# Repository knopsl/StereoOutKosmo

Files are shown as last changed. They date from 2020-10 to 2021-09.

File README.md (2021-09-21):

# Stereo output / Kosmo

Stereo output synthesizer module in Kosmo format.

This is somewhat based on the [Barton Stereo Outs](https://www.bartonmusicalcircuits.com/stereoouts/index.html)  module. There are four AC coupled inputs with pan and level controls. 

The headphone output section is based on the LM4808 datasheet circuit. This is an SMD (SOIC-8) part; all other components are through hole.

I've built this but my mechanical design was frankly stupid. I ended up kludging it together in a somewhat horrible way. I have eliminated the PCB design file and Gerbers from this repository; do better ones yourself! The circuit design is fine as far as I can see. So is the front panel except the slider mounting screws holes would be eliminated if I were to do it over.

## Photo

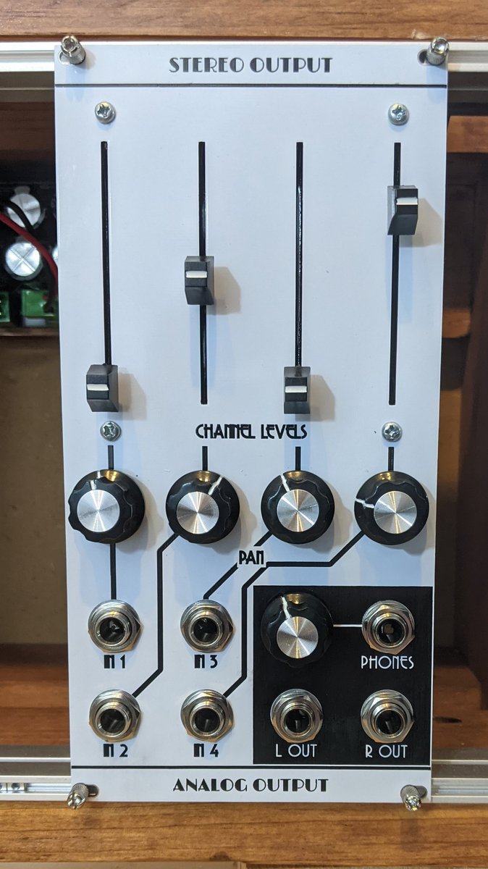
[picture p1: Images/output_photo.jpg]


## Documentation:

* [Schematic](Docs/ao_output.pdf)
* [BOM](Docs/ao_output_bom.md)

## Submodules

This repo uses submodules aoKicad and Kosmo_panel, which provide needed libaries for KiCad. To clone:

```
git clone git@github.com:holmesrichards/audiomixer.git
git submodule init
git submodule update
```

Alternatively do

```
git clone --recurse-submodules git@github.com:holmesrichards/audiomixer.git
```

Or if you download the repository as a zip file, you must also click on the "aoKicad" and "Kosmo\_panel" links on the GitHub page (they'll have "@ something" after them) and download them as separate zip files which you can unzip into this repo's aoKicad and Kosmo\_panel directories.

If desired, copy the files from aoKicad and Kosmo\_panel to wherever you prefer (your KiCad user library directory, for instance, if you have one). Then in KiCad, add symbol libraries 

```
aoKicad/ao_symbols
Kosmo_panel/Kosmo
```
and footprint libraries 
```
aoKicad/ao_tht
Kosmo_panel/Kosmo_panel.
```

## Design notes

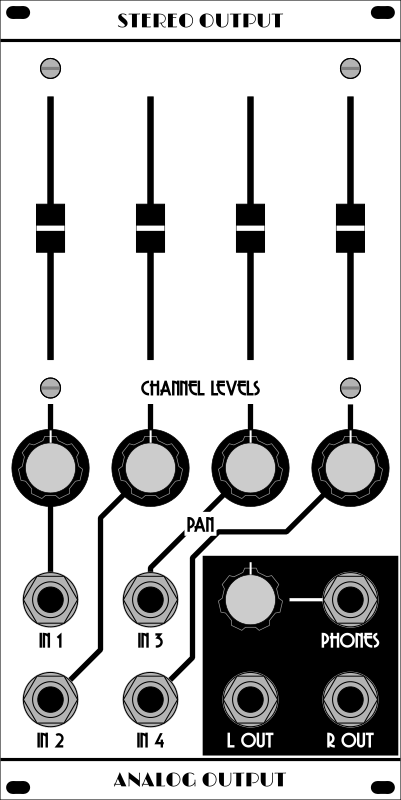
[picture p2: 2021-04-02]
Hardware/Panel/ao_output_panel_slide.png

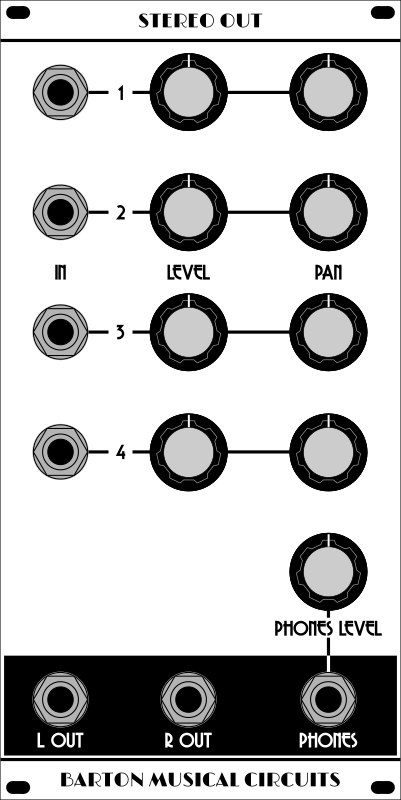
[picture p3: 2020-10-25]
Hardware/Panel/ao_output_panel.png

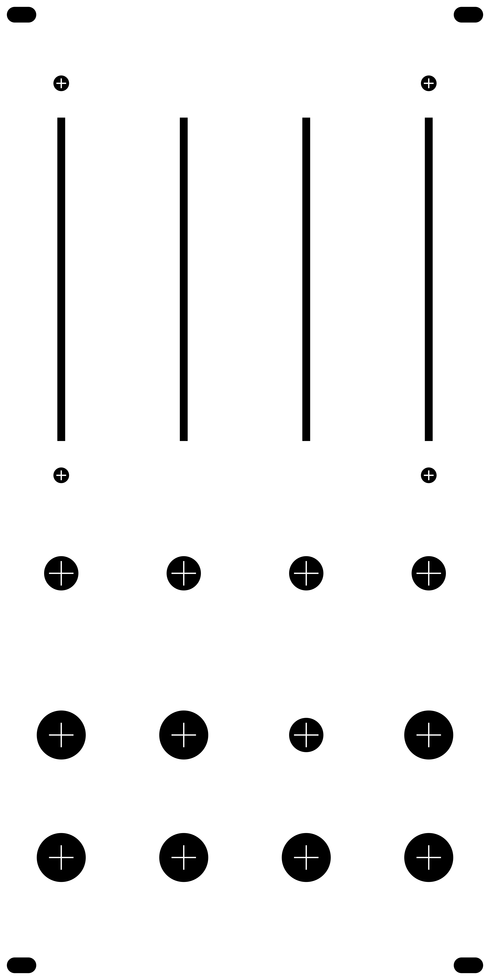
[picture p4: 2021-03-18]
Hardware/Panel/ao_output_panel_slide_holes.png

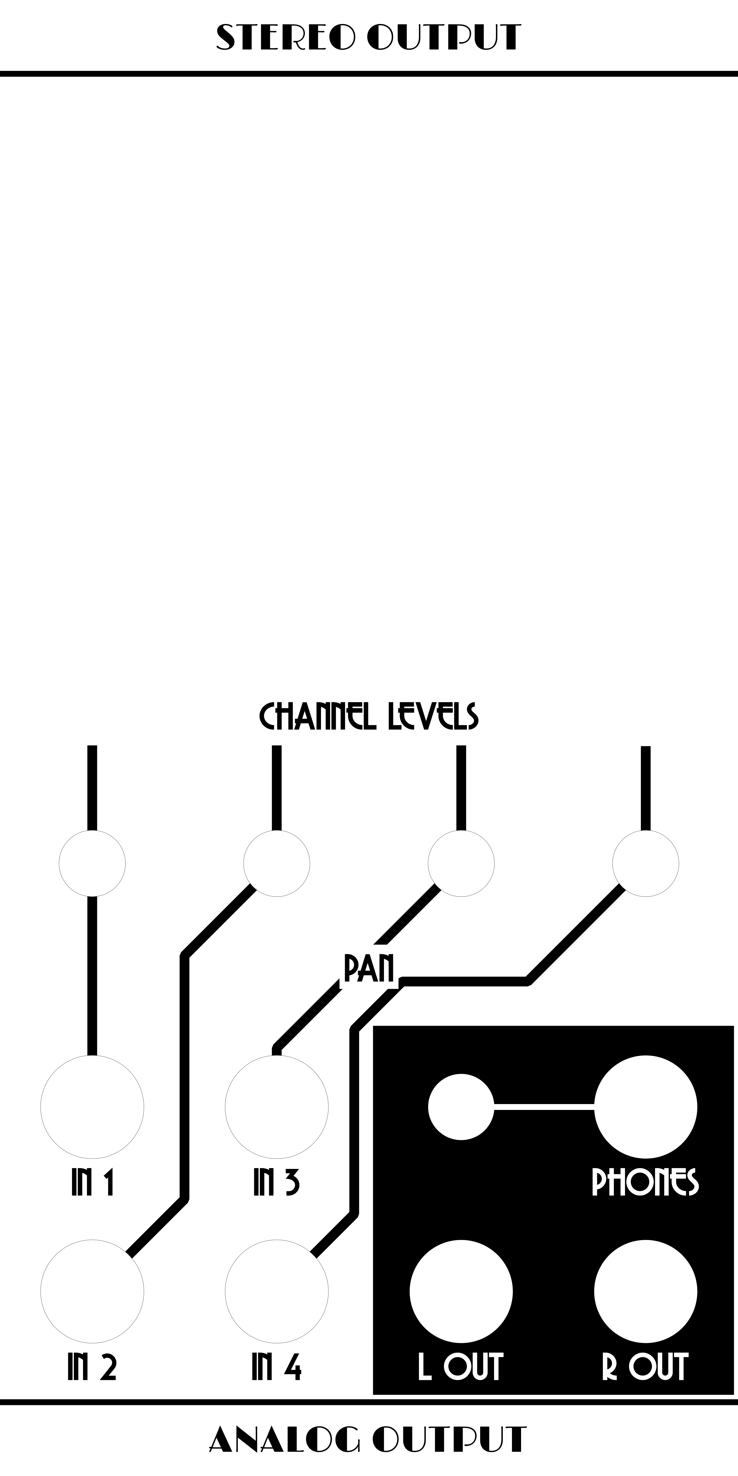
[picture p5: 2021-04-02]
Hardware/Panel/ao_output_panel_slide_art.png

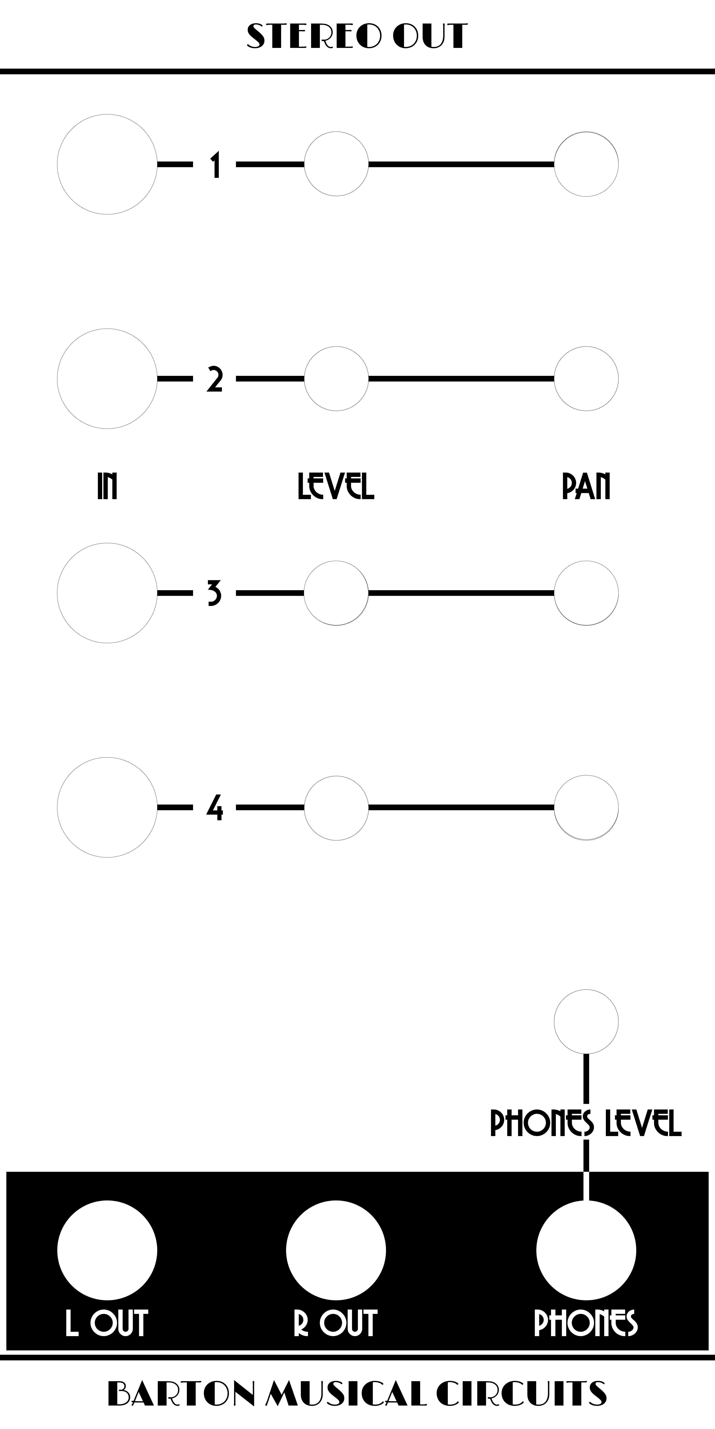
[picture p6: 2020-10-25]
Hardware/Panel/ao_output_panel_art.png

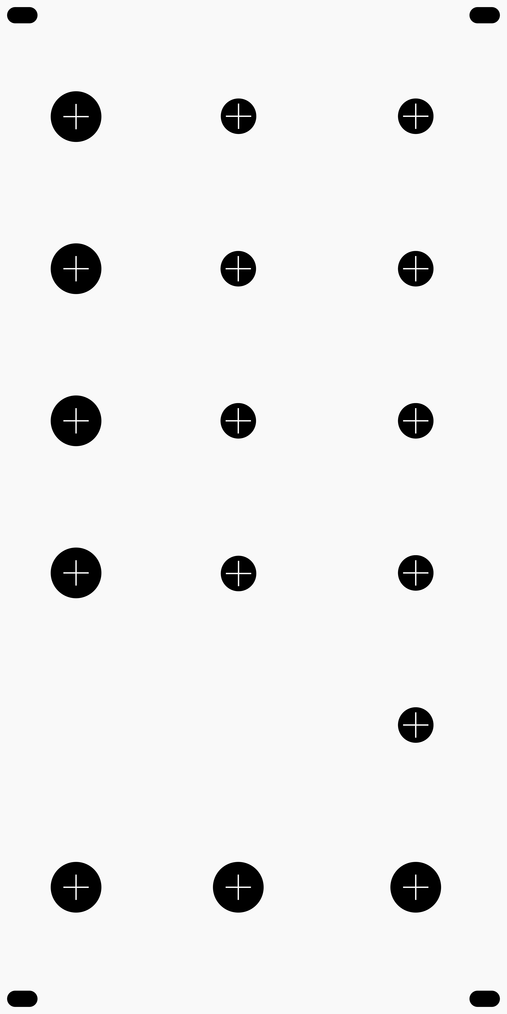
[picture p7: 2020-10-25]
Hardware/Panel/ao_output_panel_holes.png

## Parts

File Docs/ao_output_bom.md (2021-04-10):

# Analog Output Stereo Output BOM

Fri 09 Apr 2021 10:43:46 PM EDT

Generated from schematic by Eeschema 5.1.9-73d0e3b20d~88~ubuntu20.04.1

**Component Count:** 84

| Refs | Qty | Component | Description | Manufacturer | Part | Vendor |
| ----- | --- | ---- | --- | ---- | ---- | ---- |
| C1, C2, C3, C4 | 4 | 470nF | Polyester film capacitor |  |  |  |
| C5, C6 | 2 | 330pF | Ceramic capacitor |  |  |  |
| C7, C8, C9 | 3 | 2.2uF | Bipolar electrolytic capacitor |  |  |  |
| C10, C11 | 2 | 1uF* | Polyester film capacitor |  |  |  |
| C12, C13 | 2 | 10uF | Electrolytic capacitor |  |  |  |
| C14, C15, C16, C17, C19, C20 | 6 | 100nF | Ceramic capacitor |  |  |  |
| C18 | 1 | 330nF | Ceramic capacitor |  |  |  |
| D1, D2, D3, D4, D5, D6, D7, D8, D9, D10 | 10 | 1N5817 | Schottky diode |  |  |  |
| J2 | 1 | Conn_01x17 | 1x17 pin socket, 2.54 mm spacing |  |  |  |
| J3, J4, J5, J6, J7, J8 | 6 | AudioJack2 | Audio Jack, 2 Poles (Mono / TS) |  |  |  |
| J9 | 1 | AudioJack3 | Audio Jack, 3 Poles (Stereo / TRS) |  |  |  |
| J10 | 1 | Synth_power_2x5 | 2x5 pin shrouded header 2.54 mm spacing |  |  |  |
| J11 | 1 | Conn_02x05_Odd_Even | 2x5 pin header, 2.54 mm spacing |  |  |  |
| J12 | 1 | Conn_01x17 | 1x17 pin header, 2.54 mm spacing |  |  |  |
| R1, R2, R3, R4, R5, R6, R7, R8, R19, R20 | 10 | 100k | Resistor |  |  |  |
| R9, R10, R11, R12, R13, R14, R15, R16, R17, R18 | 10 | 10k | Resistor |  |  |  |
| R21, R22, R23, R24 | 4 | 3.9k | Resistor |  |  |  |
| R25, R26 | 2 | 33k | Resistor |  |  |  |
| R27, R28 | 2 | 75R | 1/2 W Resistor |  |  |  |
| R29, R30 | 2 | 1k | Resistor |  |  |  |
| RV1, RV2, RV3, RV4 | 4 | A100k | Slide potentiometer | Alpha | RA6020F | Tayda | A-4492 |
| RV5, RV6, RV7, RV8, RV9 | 5 | B10k | 9mm Dual potentiometer | Alps Alpine | RK09L12D0A1W | Mouser |
| U1 | 1 | TL074 | Quad Low-Noise JFET-Input Operational Amplifiers, DIP-14 |  |  |  |
| U2 | 1 | TL072 | Dual Low-Noise JFET-Input Operational Amplifiers, DIP-8 |  |  |  |
| U3 | 1 | LM4808 | Class-AB Stereo Headphone Driver, SOIC-8 |  |  |  |
| U4 | 1 | L78L05_TO92 | Positive 100mA 30V Linear Regulator, Fixed Output 5V, TO-92 |  |  |  |
| | 1 | | 8 pin DIP socket |  | | |
| | 1 | | 14 pin DIP socket |  | | |
| | 5 | | knobs | | | | 
| | 2 | | M3 5 mm spacer | | |  |
| | 2 | | M3 10 mm spacer | | |  |
| | 8 | | M3 6 mm screw | | | | 

J1 socket not actually fitted. Solder J11 pins to both main and slide pots boards.

\* Marked as 100 nF on PCB

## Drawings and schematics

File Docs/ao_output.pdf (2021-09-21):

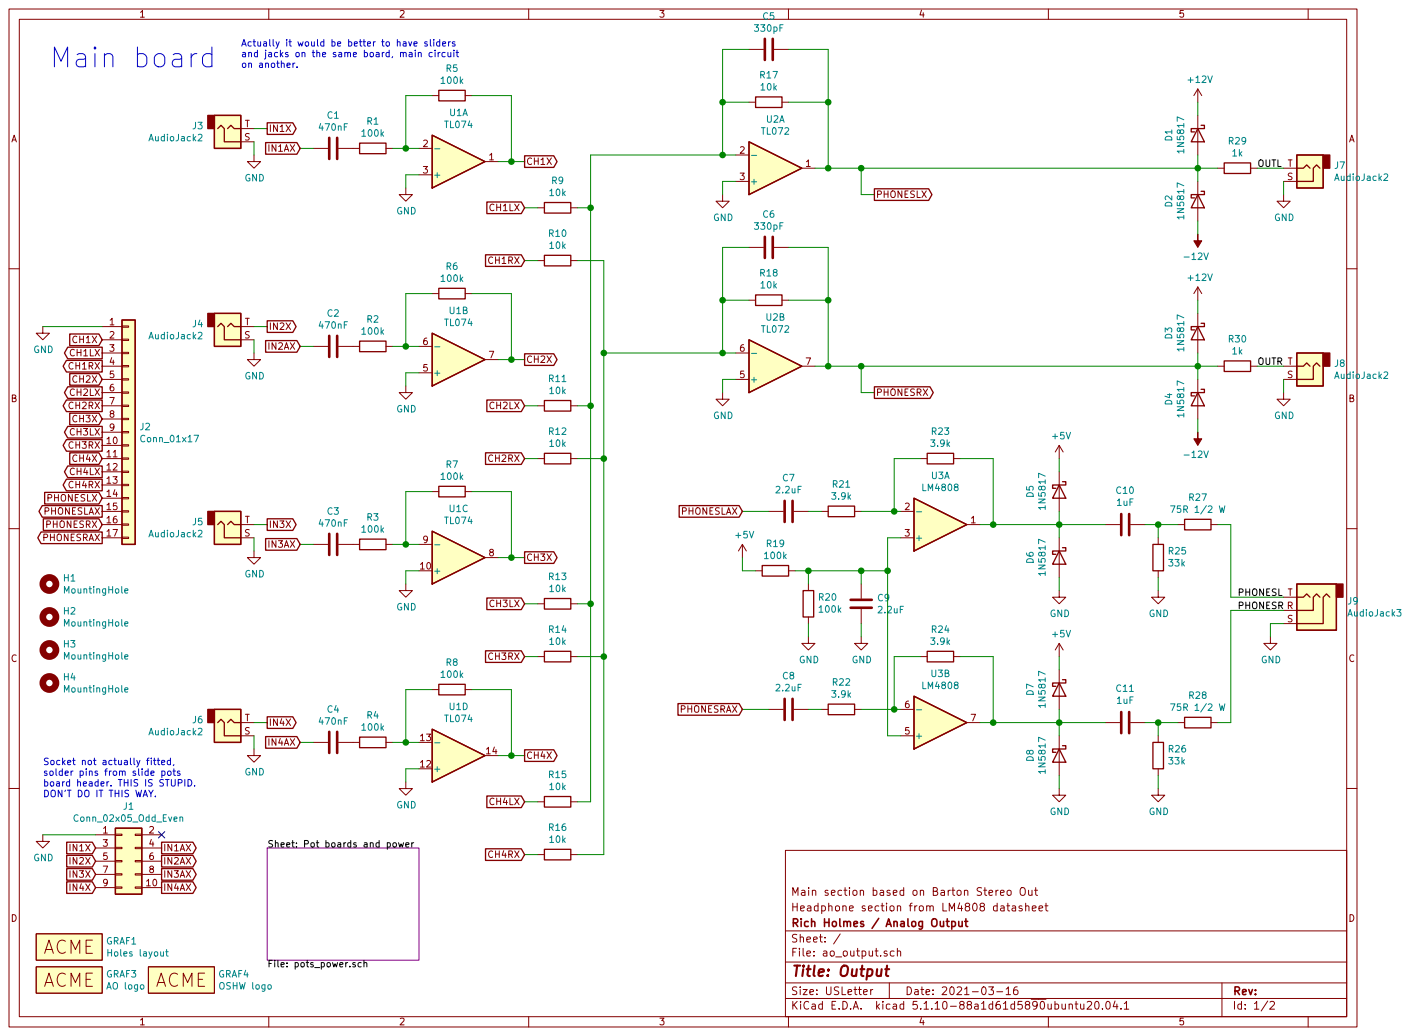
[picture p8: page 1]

solder pins from slide pots board header. THIS IS STUPID. DON'T DO IT THIS WAY. Main board

Actually it would be better to have sliders
and jacks on the same board, main circuit on another.
TL074 GND

PHONESL OUTL Socket not actually fitted,

Headphone section from LM4808 datasheet Main section based on Barton Stereo Out Sheet: Pot boards and power

File: ao_output.sch Sheet: / Rich Holmes / Analog Output

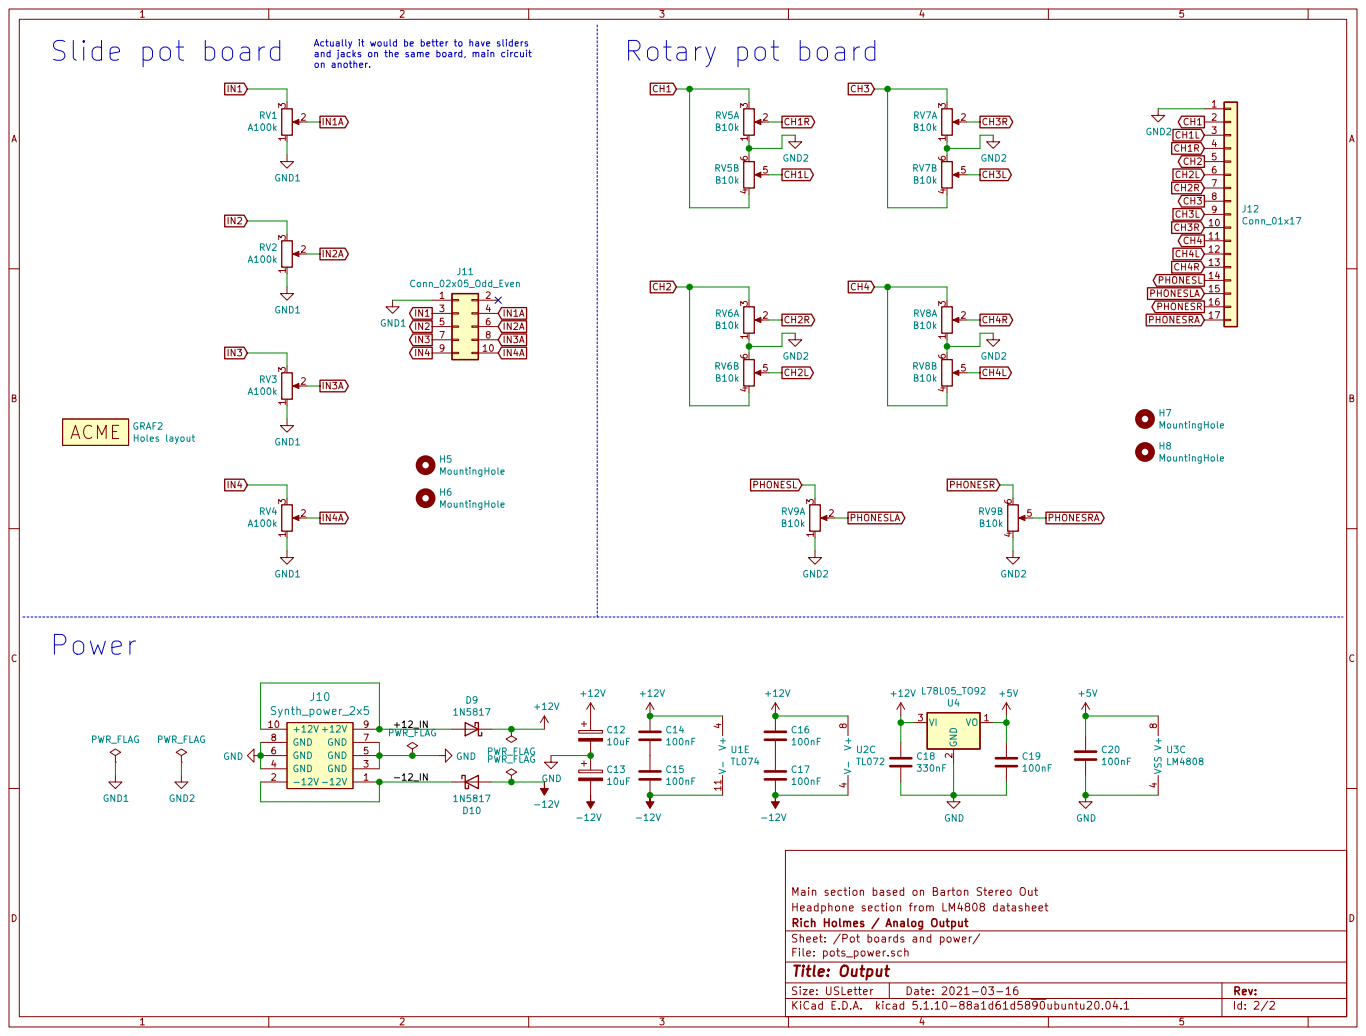
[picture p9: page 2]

and jacks on the same board, main circuit on another. Power

Actually it would be better to have sliders

Rich Holmes / Analog Output
Sheet: /Pot boards and power/
File: pots_power.sch
Id: 2/2 Title: Output

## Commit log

2020-10-25 Finalize design and add Gerbers for first PCB run
    [stereo_outs_panel-B_Cu.gbr, stereo_outs_panel-B_Mask.gbr, stereo_outs_panel-B_Paste.gbr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]
2020-11-05 Fix wrong pot orientations and touch up routing
    [stereoout-B_Cu.gbr, stereoout-B_Mask.gbr, stereoout-B_Paste.gbr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]
2021-01-02 Footprints updated
2021-02-19 Footprint update
2021-03-18 Rethink, make this a new design
    [ao_output.kicad_pcb, ao_output.sch, ao_output_panel.kicad_pcb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]
2021-03-20 Rename file; PCB logos and text; more mounting holes
    [ao_output.kicad_pcb, ao_output.sch, pots_power.sch]
2021-03-20 Pot info added
    [pots_power.sch]
2021-04-02 rm Barton Daughterboard directory; final changes before fabbing; Gerbers; docs updates
    [ao_output-B_Cu.gbr, ao_output-B_Mask.gbr, ao_output-B_Paste.gbr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]
2021-04-10 Component value changes, BOM updates
    [ao_output.sch, pots_power.sch]
2021-06-15 Reconnect pots, correct some values
    [ao_output.kicad_pcb, pots_power.sch]
2021-09-21 Libraries cleanup; rm PCB layout and Gerbers; rm images of other headphone outputs; update README and schematic
    [ao_output-B_Cu.gbr, ao_output-B_Mask.gbr, ao_output-B_Paste.gbr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]
